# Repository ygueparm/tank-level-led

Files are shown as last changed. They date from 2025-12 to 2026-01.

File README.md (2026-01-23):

🔍 **Menu de navigation rapide**
- [🔧 How It Works](#-How-It-Works)
- [📊 Calibration & Real-World Parameters](#-calibration--real-world-parameters)
- [🌟 Key Features](#-key-features)
- [🔧 Wiring Hint](#-wiring-hint)
- [🙏 Acknowledgments](#acknowledgments)

---

## 🔧 How It Works
1bar = 10 meter (approximatly)

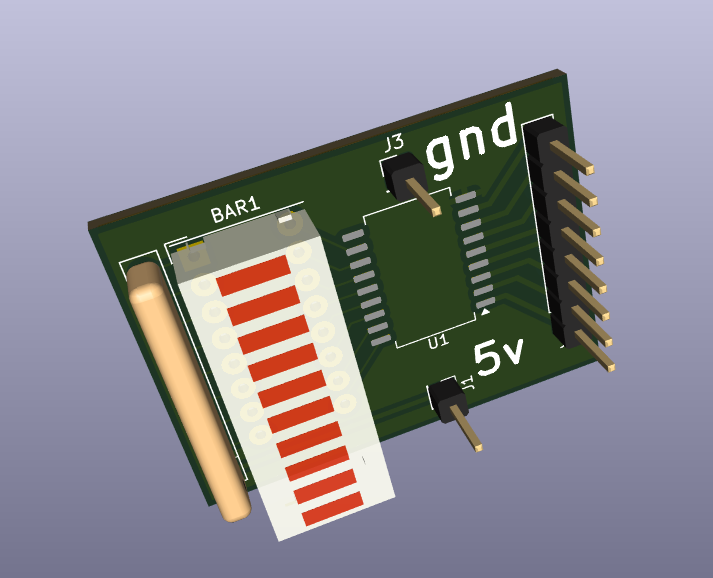
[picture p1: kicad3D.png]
3D de l'afficheur led


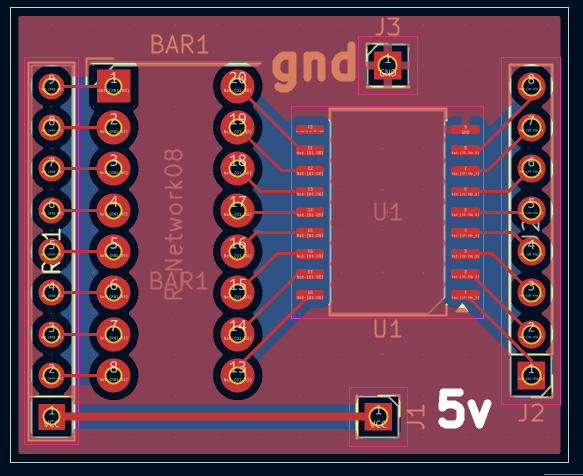
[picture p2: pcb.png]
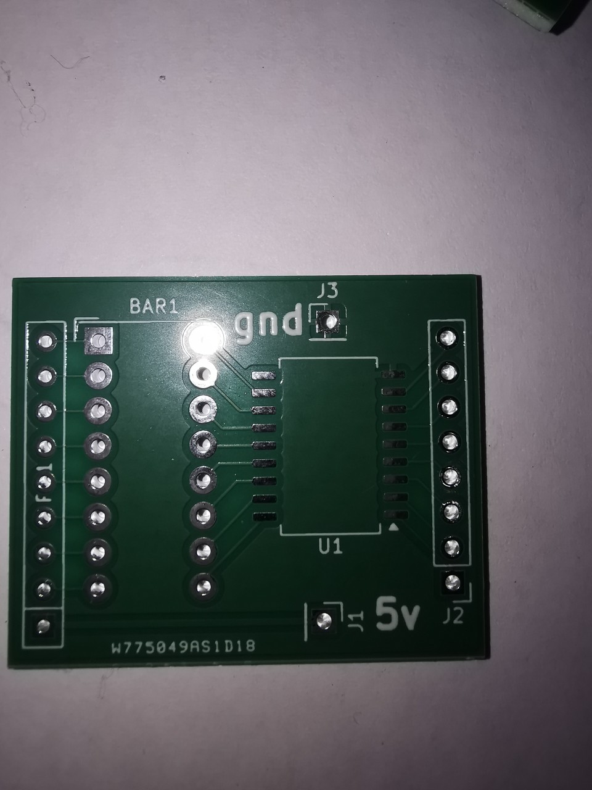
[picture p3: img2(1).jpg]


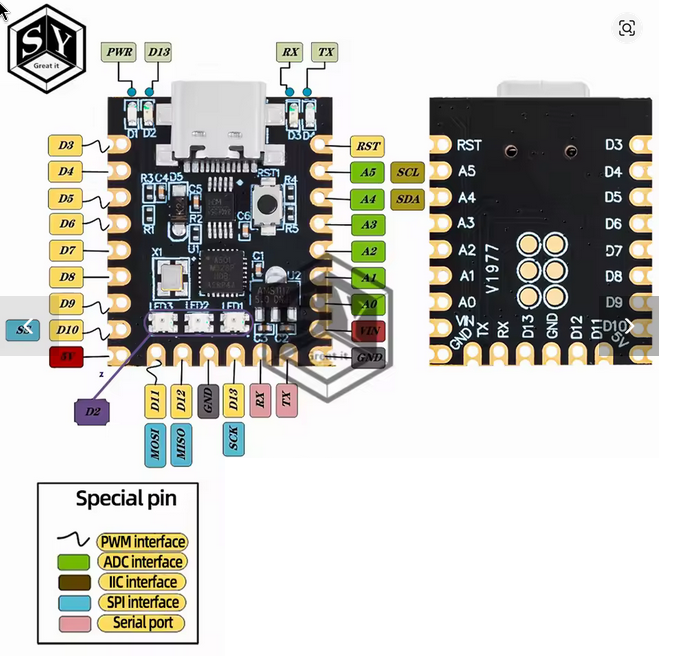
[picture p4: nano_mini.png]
arduino nano mini


This system monitors and visualizes the fill level of an underground fuel/oil tank using:

    A 0–1 bar pressure sensor (measuring static head pressure),
    An Arduino Nano for signal processing and control,
    A 8-LED bar for intuitive visual feedback,
    A solid-state relay (SSR) to automate a pump based on level thresholds.

## 📊 Calibration & Real-World Parameters

in my home my tank is outdoor, and at 2 meter, i use it for the garden, and full it with a pump from underground or rain water, so i bought a 4-20 pressure sensors t osee if i need to full it or not

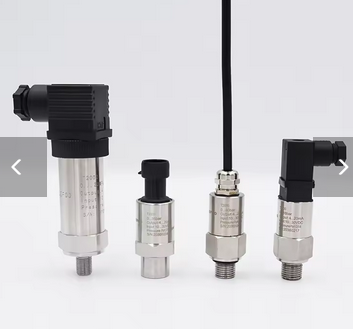
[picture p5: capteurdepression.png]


All calculations are based on empirical measurements (not just theoretical formulas), making the system robust to sensor drift or installation-specific conditions:
Parameter
	
Value
Empty tank  0.00 bar (4.28 mA)

Full tank 0.21 bar (7.46 mA)

Pump shut-off (dynamic) 0.43 bar (prevents overfill during pump operation)

Pump start threshold ≤15% level

10-sample moving average on analog readings
## 🌟 Key Features

    ✅ Startup LED test — visual confirmation of all LEDs and level simulation  
    📈 Progressive LED bar — linear mapping of pressure → fill level (0 to 8 LEDs = 0% to 100%)  
    ⚠️ Critical-level alert — first LED blinks when level ≤10% (low fuel warning)  
    🔄 Hysteresis-based pump control — avoids rapid ON/OFF cycling with a ssr you can command a pump on D11:
        Pump starts when level ≤15%  
        Pump stops when dynamic pressure ≥ 0.43 bar (measured during pumping)
    📋 Live serial dashboard — ASCII bar graph + status in real time:

```
Affichage LED: 0.00 - 0.21 bar (0.21 = toutes LEDs)
Courant: 4.28mA (0 bar) à 20.0mA (1 bar)
Pompe: Démarre à 0.15 bar / Arrête à 0.45 bar
========================================
Pression | % Remplissage | Barre LEDs | Pompe
---------|---------------|------------|------
0.000 bar | 0.0% | ░░░░░░░░ | VIDE | OFF | Courant: 0.00mA | LED%: 0.0%
Initialisation terminée - Pression: 0.000 bar
>>> État initial: POMPE ON (niveau bas) <<<
0.000 bar | 0.0%   | ░░░░░░░░ | VIDE | ON | Courant: 0.00mA | LED%: 0.0%
0.210 bar | 100.0% | ███████░ | Pleine | OFF | Courant: 7.21mA | LED%: 100.0%
```

## 📐 Wiring Hint

    Sensor → analogPin (via shunt resistor for 4–20 mA loop)  
    LEDs → digital pins (simple HIGH/LOW, no PWM needed)  
    SSR control → pinSSR → triggers external pump contactor

    🔧 Note: The linear conversion convertirPressionReelle() uses real current-to-pressure calibration points — easily adaptable to other sensors.

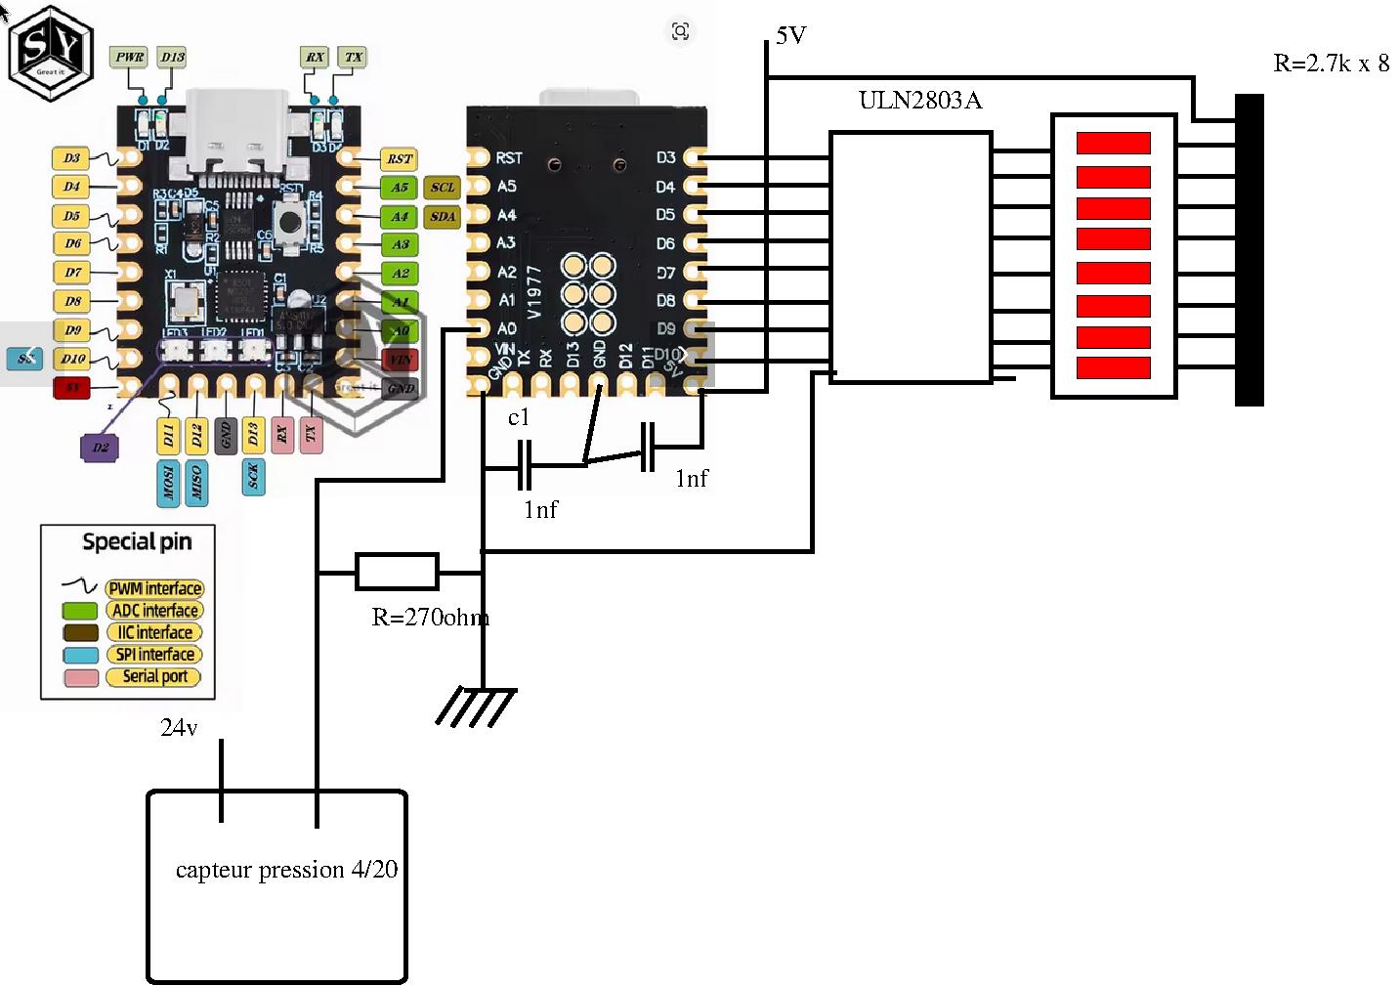
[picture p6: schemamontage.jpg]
schema de montage

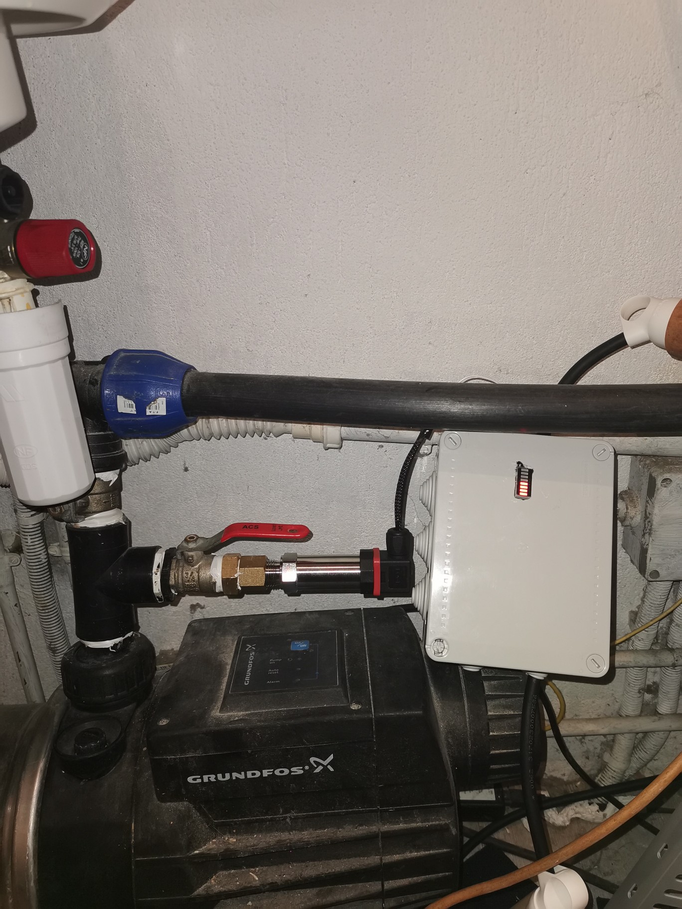
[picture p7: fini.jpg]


# Acknowledgments

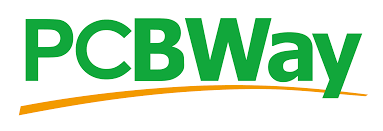
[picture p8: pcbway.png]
pcbway


This project wouldn’t be where it is today without the generous support of the open-source hardware community—and especially **[PCBWay](https://www.pcbway.com/)**.

 I was able to fabricate a revised version (**v1.1**) of the tank-level LED controller board. The original design contained a subtle but critical pin assignment error 

Having access to physical prototypes at no cost allowed me to:
- ✅ Identify and confirm the hardware bug,
- ✅ Iterate on the layout with confidence,
- ✅ Validate signal integrity and power distribution,
- ✅ And ultimately deliver a more reliable, functional design.

PCBWay’s commitment to empowering independent developers, students, and hobbyists like me truly accelerates innovation at the grassroots level. Their fast turnaround, consistent quality, and maker-friendly approach make them a standout partner in the electronics ecosystem.

A sincere thank you to the PCBWay team—you’ve helped turn a flawed prototype into a working solution! 🙏 and i am very proud to be selected by your team

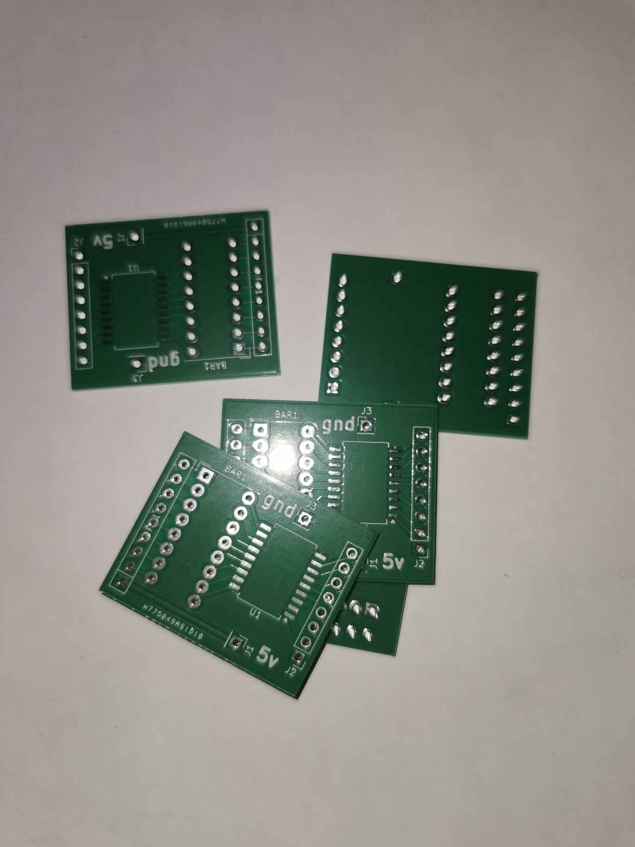
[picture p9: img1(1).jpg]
pcb


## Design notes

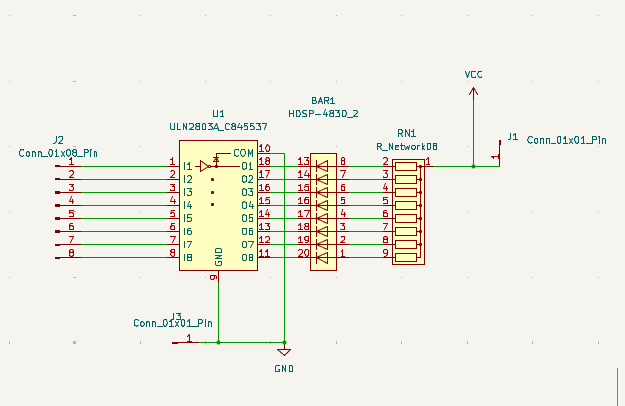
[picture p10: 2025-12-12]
kicadsch.png

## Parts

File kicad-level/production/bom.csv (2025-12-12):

Designator | Footprint | Quantity | Value | LCSC Part #
BAR1 | HDSP-4830 | 1 | HDSP-4830_2
J1, J3 | PinHeader_1x01_P2.54mm_Vertical | 2 | Conn_01x01_Pin
J2 | PinHeader_1x08_P2.54mm_Vertical | 1 | Conn_01x08_Pin
RN1 | R_Array_SIP9 | 1 | R_Network08
U1 | SOP-18_7x12.5mm_P1.27mm | 1 | ULN2803A_C845537

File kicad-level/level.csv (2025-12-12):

Id | Référence | Empreinte | Quantité | Désignation | Fournisseur et réf
1 | U1 | SOP-18_7x12.5mm_P1.27mm | 1 | ULN2803A
2 | RN1 | R_Array_SIP9 | 1 | R_Network08
3 | J2 | PinHeader_1x08_P2.54mm_Vertical | 1 | Conn_01x08_Pin
4 | J1 | PinHeader_1x01_P2.54mm_Vertical | 1 | Conn_01x01_Pin
5 | BAR1 | HDSP-4830 | 1 | HDSP-4830_2

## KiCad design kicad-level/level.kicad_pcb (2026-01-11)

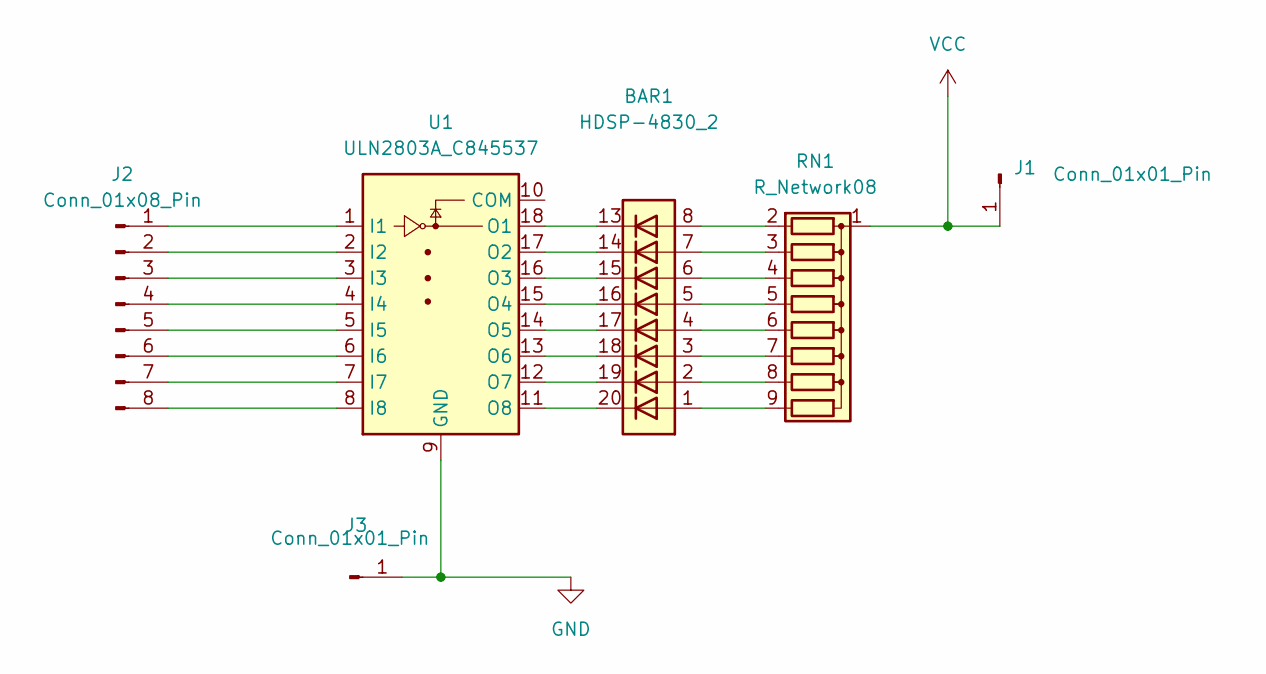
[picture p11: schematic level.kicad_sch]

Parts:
BAR1: HDSP-4830_2; HDSP-4830
J1, J3: Conn_01x01_Pin; PinHeader_1x01_P2.54mm_Vertical
J2: Conn_01x08_Pin; PinHeader_1x08_P2.54mm_Vertical
RN1: R_Network08; R_Array_SIP9
U1: ULN2803A_C845537; SOP-18_7x12.5mm_P1.27mm

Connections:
GND: J3.1, U1.9 (GND)
unnamed: J2.1, U1.1 (I1)
unnamed: J2.2, U1.2 (I2)
unnamed: J2.3, U1.3 (I3)
unnamed: J2.4, U1.4 (I4)
unnamed: J2.5, U1.5 (I5)
unnamed: J2.6, U1.6 (I6)
unnamed: J2.7, U1.7 (I7)
unnamed: J2.8, U1.8 (I8)
unnamed: BAR1.8 (A), RN1.2 (R1)
unnamed: BAR1.7 (A), RN1.3 (R2)
unnamed: BAR1.6 (A), RN1.4 (R3)
unnamed: BAR1.5 (A), RN1.5 (R4)
unnamed: BAR1.4 (A), RN1.6 (R5)
unnamed: BAR1.3 (A), RN1.7 (R6)
unnamed: BAR1.2 (A), RN1.8 (R7)
unnamed: BAR1.1 (A), RN1.9 (R8)
unnamed: BAR1.13 (K), U1.18 (O1)
unnamed: BAR1.14 (K), U1.17 (O2)
unnamed: BAR1.15 (K), U1.16 (O3)
unnamed: BAR1.16 (K), U1.15 (O4)
unnamed: BAR1.17 (K), U1.14 (O5)
unnamed: BAR1.18 (K), U1.13 (O6)
unnamed: BAR1.19 (K), U1.12 (O7)
unnamed: BAR1.20 (K), U1.11 (O8)
VCC: J1.1, RN1.1 (common)

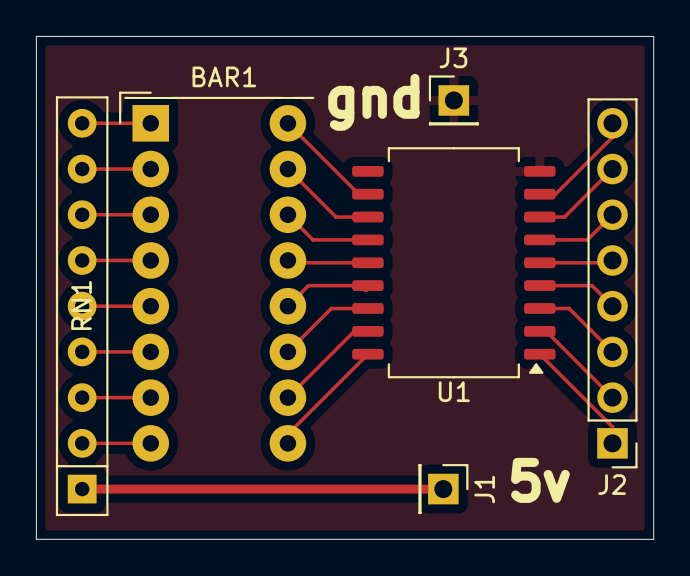
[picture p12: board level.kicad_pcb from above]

Board: 2 copper layers, 34.3 x 27.9 mm, 6 parts (0 on the bottom side), 26 nets.

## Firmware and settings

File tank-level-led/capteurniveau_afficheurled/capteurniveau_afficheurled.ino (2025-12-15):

#include <Arduino.h>

const int analogPin = A0;
const float R_shunt = 217.0;
const int numReadings = 10;

// Pins des LEDs (D3 à D10)
const int leds[] = {3, 4, 5, 6, 7, 8, 9, 10};
const int nbLeds = 8;

// Pin pour le SSR de la pompe
const int pinSSR = 11;

// Seuils de démarrage et arrêt de la pompe
const float seuilDemarragePompe = 15.0;  // Démarre à 15% de remplissage
const float seuilArretPompe = 95.0;      // S'arrête à 95% (plein -5%)
const float pressionArretPompe = 0.45;   // Pression seuil d'arrêt reel mesuré lors d'essai (0.45 bar)

// === PLAGE COMPLÈTE pour affichage pression : 0-1 BAR ===
const float courantVide = 4.28;      // 4.28mA = 0.00 bar mesure reel a modifié suivant le capeur
const float courantPleine = 20.0;    // 20.0mA = 1.00 bar (standard) a rempalcé suivant le capteur utilisé

const float pressionMin = 0.00;      // 0% = 0.00 bar
const float pressionMax = 1.00;      // 100% = 1.00 bar pareil a mettre a jour suivant le capteur utilisé

// === PLAGE LIMITÉE pour affichage LED : 0-0.21 BAR ===
const float pressionMaxLED = 0.21;   // 0.21 bar = toutes les LEDs allumées

// Variables pour la moyenne glissante
int readings[numReadings];
int readIndex = 0;
int total = 0;
int average = 0;

// Pour l'affichage série périodique
unsigned long previousMillis = 0;
const unsigned long affichageInterval = 5000;

// Dernière pression pour éviter les mises à jour inutiles des LEDs
float dernierePression = -1.0;

// État de la pompe
bool pompeActive = false;
bool initialisationTerminee = false;

void setup() {
  Serial.begin(9600);
  
  // Initialiser toutes les LEDs en sortie
  for (int i = 0; i < nbLeds; i++) {
    pinMode(leds[i], OUTPUT);
    digitalWrite(leds[i], LOW);
  }
  
  // Initialiser le pin du SSR
  pinMode(pinSSR, OUTPUT);
  digitalWrite(pinSSR, LOW);
  
  // Initialiser le tableau des mesures
  for (int i = 0; i < numReadings; i++) {
    readings[i] = 0;
  }
  
  
  // Test des LEDs au démarrage
  testLeds();
  
  Serial.println("========================================");
  Serial.println("CAPTEUR NIVEAU CUVE");
  Serial.println("Affichage pression: 0.00 - 1.00 bar");
  Serial.println("Affichage LED: 0.00 - 0.21 bar (0.21 = toutes LEDs)");
  Serial.println("Courant: 4.28mA (0 bar) à 20.0mA (1 bar)");
  Serial.println("Pompe: Démarre à 0.15 bar / Arrête à 0.45 bar");
  Serial.println("========================================");
  Serial.println("Pression | % Remplissage | Barre LEDs | Pompe");
  Serial.println("---------|---------------|------------|------");
}

void loop() {
  // Mise à jour de la moyenne glissante
  total = total - readings[readIndex];
  readings[readIndex] = analogRead(analogPin);
  total = total + readings[readIndex];
  readIndex = (readIndex + 1) % numReadings;
  average = total / numReadings;
  
  // Calcul de la pression
  float voltage = average * (5.0 / 1023.0);
  float courant = (voltage / R_shunt) * 1000;
  
  // === CONVERSION POUR AFFICHAGE : 0-1 bar ===
  float pression = convertir4_20mA_vers_Bar(courant);
  
  // Phase d'initialisation
  static int compteurInit = 0;
  if (!initialisationTerminee) {
    compteurInit++;
    if (compteurInit >= numReadings * 2) {
      initialisationTerminee = true;
      Serial.print("Initialisation terminée - Pression: ");
      Serial.print(pression, 3);
      Serial.println(" bar");
      
      float pourcentageLED = mapFloat(pression, 0.0, pressionMaxLED, 0.0, 100.0);
      if (pourcentageLED <= seuilDemarragePompe) {
        pompeActive = true;
        digitalWrite(pinSSR, HIGH);
        Serial.println(">>> État initial: POMPE ON (niveau bas) <<<");
      } else {
        pompeActive = false;
        digitalWrite(pinSSR, LOW);
        Serial.println(">>> État initial: POMPE OFF (niveau suffisant) <<<");
      }
    }
  }
  
  // Mettre à jour l'affichage LED si changement significatif
  if (abs(pression - dernierePression) > 0.01) {
    dernierePression = pression;
  }
  
  // Mettre à jour les LEDs (avec plage limitée 0-0.21 bar)
  afficherNiveauLEDs(pression);
  
  // Gestion de la pompe (utilise la pression réelle 0-1 bar)
  if (initialisationTerminee) {
    gererPompe(pression);
  }
  
  // Affichage série toutes les 5 secondes
  unsigned long currentMillis = millis();
  if (currentMillis - previousMillis >= affichageInterval) {
    previousMillis = currentMillis;
    
    // Pourcentage basé sur 0-1 bar
    float pourcentageReel = pression * 100.0;
    
    // Pourcentage pour l'affichage LED (0-0.21 bar)
    float pourcentageLED = mapFloat(pression, 0.0, pressionMaxLED, 0.0, 100.0);
    pourcentageLED = constrain(pourcentageLED, 0.0, 100.0);
    
    // Nombre de LEDs allumées (basé sur 0-0.21 bar)
    int ledsAllumees = mapFloat(pression, 0.0, pressionMaxLED, 0, nbLeds);
    ledsAllumees = constrain(ledsAllumees, 0, nbLeds);
    
    // Affichage formaté
    Serial.print(pression, 3);
    Serial.print(" bar | ");
    Serial.print(pourcentageReel, 1);  // Pourcentage réel 0-100%
    Serial.print("% | ");
    
    // Barre graphique (basée sur 0-0.21 bar)
    for (int i = 0; i < nbLeds; i++) {
      Serial.print(i < ledsAllumees ? "█" : "░");
    }
    
    // État texte (basé sur affichage LED)
    Serial.print(" | ");
    if (pourcentageLED <= 5.0) {
      Serial.print("VIDE");
    } else if (pression >= pressionMaxLED) {
      Serial.print("MAX LED");
    } else if (pourcentageLED >= 95.0) {
      Serial.print("PLEINE");
    } else {
      Serial.print("Niveau ");
      Serial.print(ledsAllumees);
    }
    
    // État de la pompe
    Serial.print(" | ");
    Serial.print(pompeActive ? "ON" : "OFF");
    
    // Info supplémentaire
    Serial.print(" | Courant: ");
    Serial.print(courant, 2);
    Serial.print("mA | LED%: ");
    Serial.print(pourcentageLED, 1);
    Serial.println("%");
  }
  
  delay(50);
}

// Conversion 4-20mA → 0-1 bar
float convertir4_20mA_vers_Bar(float courant) {
  courant = constrain(courant, courantVide, courantPleine);
  return (courant - courantVide) * (pressionMax - pressionMin) / 
         (courantPleine - courantVide);
}

// Gestion de la pompe (utilise pression 0-1 bar)
void gererPompe(float pression) {
  // Pour la pompe, on utilise la pression réelle (0-1 bar)
  // ou on peut convertir en pourcentage LED si préféré
  float pourcentageLED = mapFloat(pression, 0.0, pressionMaxLED, 0.0, 100.0);
  
  if (!pompeActive && pourcentageLED <= seuilDemarragePompe) {
    pompeActive = true;
    digitalWrite(pinSSR, HIGH);
    Serial.println(">>> POMPE DÉMARRÉE (niveau bas) <<<");
  } 
  else if (pompeActive && pression >= pressionArretPompe) {
    pompeActive = false;
    digitalWrite(pinSSR, LOW);
    Serial.print(">>> POMPE ARRÊTÉE (");
    Serial.print(pression, 3);
    Serial.println(" bar atteints) <<<");
  }
}

// Affichage sur les LEDs (PLAGE LIMITÉE 0-0.21 bar)
void afficherNiveauLEDs(float pression) {
  // Convertir pression 0-1 bar → plage LED 0-0.21 bar
  float pressionLED = min(pression, pressionMaxLED);
  float pourcentageLED = mapFloat(pressionLED, 0.0, pressionMaxLED, 0.0, 100.0);
  
  int ledsAllumees = mapFloat(pressionLED, 0.0, pressionMaxLED, 0, nbLeds);
  ledsAllumees = constrain(ledsAllumees, 0, nbLeds);
  
  // Si pression > 0.21 bar, on fait clignoter la dernière LED
  static unsigned long dernierClignotement = 0;
  static bool etatClignotement = false;
  
  if (pression > pressionMaxLED) {
    // Mode dépassement : dernière LED clignote
    if (millis() - dernierClignotement >= 500) {
      dernierClignotement = millis();
      etatClignotement = !etatClignotement;
    }
    
    // Toutes les LEDs allumées + dernière clignote
    for (int i = 0; i < nbLeds - 1; i++) {
      digitalWrite(leds[i], HIGH);
    }
    digitalWrite(leds[nbLeds - 1], etatClignotement ? HIGH : LOW);
  }
  else if (pourcentageLED <= 10.0) {
    // Clignotement niveau critique (≤10%)
    if (millis() - dernierClignotement >= 1000) {
      dernierClignotement = millis();
      etatClignotement = !etatClignotement;
    }
    
    digitalWrite(leds[0], etatClignotement ? HIGH : LOW);
    for (int i = 1; i < nbLeds; i++) {
      digitalWrite(leds[i], LOW);
    }
  } else {
    // Affichage normal
    for (int i = 0; i < nbLeds; i++) {
      digitalWrite(leds[i], i < ledsAllumees ? HIGH : LOW);
    }
  }
}

// Test des LEDs au démarrage
void testLeds() {
  Serial.println("Test LEDs: 0.00 → 0.21 bar");
  
  // Simulation de 0.00 à 0.21 bar
  for (float p = 0.00; p <= pressionMaxLED; p += 0.03) {
    int ledsAllumees = mapFloat(p, 0.0, pressionMaxLED, 0, nbLeds);
    ledsAllumees = constrain(ledsAllumees, 0, nbLeds);
    
    Serial.print("Pression: ");
    Serial.print(p, 2);
    Serial.print(" bar → LEDs: ");
    Serial.println(ledsAllumees);
    
    for (int i = 0; i < nbLeds; i++) {
      digitalWrite(leds[i], i < ledsAllumees ? HIGH : LOW);
    }
    delay(300);
  }
  
  // Test dépassement (clignotement dernière LED)
  Serial.println("Test dépassement (>0.21 bar)");
  for (int i = 0; i < 10; i++) {
    digitalWrite(leds[nbLeds - 1], HIGH);
    delay(300);
    digitalWrite(leds[nbLeds - 1], LOW);
    delay(300);
  }
  
  // Éteindre toutes les LEDs
  for (int i = 0; i < nbLeds; i++) {
    digitalWrite(leds[i], LOW);
  }
  delay(500);
}

// Fonction map pour les floats
float mapFloat(float x, float in_min, float in_max, float out_min, float out_max) {
  return (x - in_min) * (out_max - out_min) / (in_max - in_min) + out_min;
}

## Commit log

2025-12-12 ajout du .ino pour gerer l'afficheur et la pompe
2025-12-12 ajout des fichier kicad pour avoir le module led proprement commandé
    [bom.csv, designators.csv, level.csv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]
2025-12-14 correction demarrage pompe niveua intermeiaure
    [capteurniveau_afficheurled.ino]
2025-12-15 plage de pression complete, et affichage unniquement sur 0 0.21
2025-12-19 erreur pcb, com a la masse
    [level.kicad_pcb, level.kicad_sch]
2026-01-04 Revert "erreur pcb, com a la masse"
    This reverts commit de789b6cb290ad22ceee4c73f03ad83cfbf3b982.
    [level.kicad_pcb, level.kicad_sch]
2026-01-04 ajout schema de montage
2026-01-04 ajout schema de montage dans le readme
2026-01-07 misa a jour pcb plus petit
    [level.kicad_pcb, level.kicad_sch, positions.csv]
2026-01-08 capture ecran pcb
2026-01-08 captur eecran pcb dans readme
2026-01-11 ajout remerciement pcbway
    [level.kicad_pcb, positions.csv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]
2026-01-17 Add files via upload
    pcb receive !
2026-01-17 Update README.md
    add photo of pcb
